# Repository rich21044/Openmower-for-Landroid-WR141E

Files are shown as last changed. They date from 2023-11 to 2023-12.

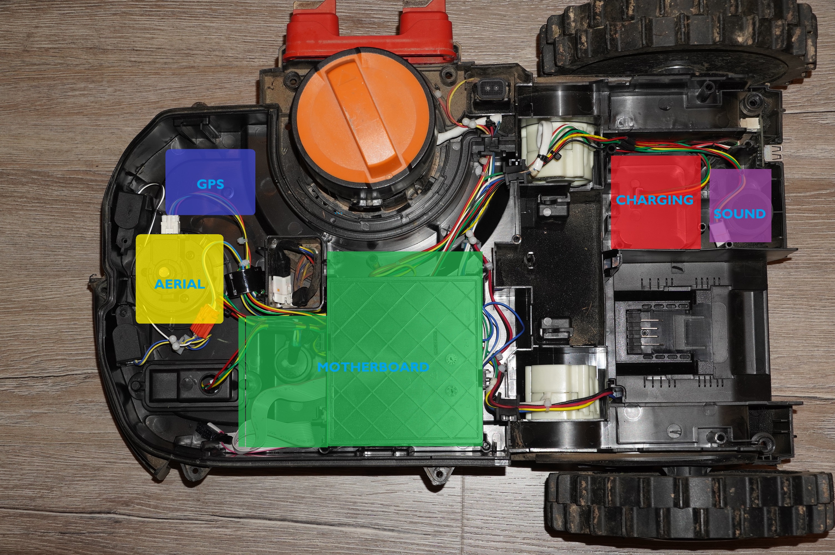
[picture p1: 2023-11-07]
Photos/WR141E Module locations.jpg

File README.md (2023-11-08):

# Openmower-for-Landroid-WR141E
Taking the hardware developed as part of ClemensElfleins work on Openmower and adapting it to fit a 2019 Landroid WR141E.

This is my first venture into Github so it might get a bit clunky. 
Usual rules apply.. please try to be constructive, I'm learning as I go so if you're going to leave some negative feedback have the grace to tell me why and how I can put it right.

The Openmower project by ClemensElflein started all this for me and I've been so fed up with the performance (or lack thereof) of my Landroid WR141E that I considered selling it and then just buying his kit
however, the Landroid does have cut to edge capability that the Open mower doesnt have and when all is said and done it probably works out at about the same cost.

According to the Gurus on Discord, the firmware in the Landroid is encoded, the data streams between the processors is encoded, the main processor is read locked and the JTAG interface is disabled.
I dont have the knowledge, expertise or equipment to hack into the exiitng Landroid hardware so the plan is to make best use of the Openmower hardware and firmware thats already been developed 
and port it into the Landroid WR141E.

The main thrust of this first stage of the project is to adjust the Openmower motherboard to fit into the available space in the Landroid.

I am also discussing development and asking questions on Discord as @Slartibartfast

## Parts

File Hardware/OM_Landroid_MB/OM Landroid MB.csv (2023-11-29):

Source: | C:\Users\matth\Documents\GitHub\Openmower-for-Landroid-WR141E\Hardware\OM_Landroid_MB\OM Landroid MB.kicad_sch
Date: | 28/11/2023 14:37
Tool: | Eeschema 7.0.8
Generator: | C:\Program Files\KiCad\7.0\bin\scripting\plugins/bom_csv_grouped_by_value_with_fp.py
Component Count: | 136
Ref | Qnty | Value | Price ea | Total | Vendor | Part No | Cmp name | Footprint | Description | Vendor | DNP
AC1201 | 1 | LSM6DSOTR | € 6.63 | € 6.63 | Digikey | 497-18367-1-ND | LSM6DSOTR | MyModules:LGA-14_2.5X3X0.86_ | IMUs - Inertial Measurement Units iNEMO inertial module: 3D accelerometer and 3D gyroscope
C1, C5, C25 | 3 | 100nF | € 0.09 | € 0.27 | Digikey | 1276-1003-1-ND | C | Capacitor_SMD:C_0805_2012Metric_Pad1.18x1.45mm_HandSolder | Unpolarized capacitor
C2, C4, C7, C8,C6,C3 | 6 | 220uF | € 1.33 | € 7.98 | Digikey | 10-EEH-AZA1V221BCT-ND | C_Polarized | Capacitor_THT:CP_Radial_D10.0mm_P5.00mm | Polarized capacitor LCSC 220uF 63V
C9, C23 | 2 | 680uF | € 2.47 | € 4.94 | Digikey | 10-EEH-ZS1V681UPCT-ND | C_Polarized | Capacitor_SMD:CP_Elec_10x10.5 | (LCSC 680uF 35V) Polarized capacitor SMD 10.30x10.30
C11, C12 | 2 | 4.7uF | € 0.28 | € 0.56 | Digikey | 1276-3179-1-nd | C | Capacitor_SMD:C_1206_3216Metric | Unpolarized capacitor
C13, C14 | 2 | 1uF | € 0.10 | € 0.20 | Digikey | 1276-1029-1-nd | C | Capacitor_SMD:C_0805_2012Metric | Unpolarized capacitor
C15, C18, C19, C24, C26 | 5 | 0.1uF | € 0.09 | € 0.45 | Digikey | 1276-1935-1-nd | C | Capacitor_SMD:C_0603_1608Metric | Unpolarized capacitor
C16, C20, C21, C22 | 4 | 22uF | € 0.32 | € 1.28 | Digikey | 1276-3148-1-nd | C | Capacitor_SMD:C_1206_3216Metric | Unpolarized capacitor
C17 | 1 | 2.2uF | € 0.17 | € 0.17 | Digikey | 1276-1183-1-nd | C | Capacitor_SMD:C_0603_1608Metric | Unpolarized capacitor
D1 | 1 | D_Schottky |  | € - |  |  | D_Schottky | Diode_SMD:D_SOD-123F | 60V 1A Schottky diode (LCSC Discontinued)
D4, D5, D6, D7, D8, D9, D10, D11, D12 | 9 | DNP |  | € - |  |  | D_TVS | Diode_SMD:D_SMB | Bidirectional transient-voltage-suppression diode
D13, D14 | 2 | DNP |  | € - |  |  | D_Zener | Diode_SMD:D_SOD-123F | Zener diode
D18, D19, D20 | 3 | DNP |  | € - |  |  | D_TVS | Diode_SMD:D_SMA | Bidirectional transient-voltage-suppression diode
D23 | 1 | LED | € 0.18 | € 0.18 | Digikey | 732-4983-1-ND | LED Green | LED_SMD:LED_0805_2012Metric | Light emitting diode
D25 | 1 | WS2812B | € 0.57 | € 0.57 | Digikey | 1568-COM-16347CT-ND | WS2812B | LED_SMD:LED_WS2812B_PLCC4_5.0x5.0mm_P3.2mm | RGB LED with integrated controller
F2, F4 | 2 | Fuse |  | € - |  |  | Fuse | MyModules:Fuseholder5x20_horiz_open_inline_Type-I | Fuse
IC1 | 1 | 74ALVC164245DGG,11 | € 1.00 | € 1.00 | Digikey | 1727-4290-1-ND | 74ALVC164245DGG,11 | 74ALVC164245DGG:SOP50P810X120-48N 48-TFSOP | 74ALVC164245 - 16-bit dual supply translating transceiver; 3-state@en-us
IC2 | 1 | TSC101CILT | € 2.03 | € 2.03 | Digikey | 497-6947-1-ND | TSC101CILT | TSC101CILT:SOT95P280X145-5N | TSC101CILT, Current Sensing Amplifier Single 5-Pin SOT-23
IC3 | 1 | MAX20405AFOC_VY+ | € 4.16 | € 4.16 | Digikey | 175-MAX20405AFOC/VY+-ND | MAX20405AFOC_VY+T | MAX2040:MAX2040 | 36V 4A/5A/6A Sync Low Iq Buck Converter in P90
J1 | 1 | Conn_01x02_Pin |  |  |  |  | Conn_01x02_Pin | Connector_JST:JST_XH_B2B-XH-AM_1x02_P2.50mm_Vertical | Generic connector, single row, 01x02, script generated
J2 | 1 | Conn_02x03_Top_Bottom | € 1.56 | € 1.56 | Digikey | A107227-ND | Conn_02x03_Odd_Even | Landroid_Motor_Conn:TE_179841 | Generic connector, double row, 02x03, odd/even pin numbering scheme (row 1 odd numbers, row 2 even numbers), script generated (kicad-library-utils/schlib/autogen/connector/)
J5, J6, J19 | 3 | Conn_01x04 |  |  |  |  | Conn_01x04 | Connector_JST:JST_XH_B4B-XH-A_1x04_P2.50mm_Vertical | Generic connector, single row, 01x04, script generated (kicad-library-utils/schlib/autogen/connector/)
J11, J12, J13, J14 | 4 | Conn_01x03_Male |  |  |  |  | Conn_01x03_Male | Connector_JST:JST_XH_B3B-XH-A_1x03_P2.50mm_Vertical | Generic connector, single row, 01x03, script generated (kicad-library-utils/schlib/autogen/connector/)
J15, J25, J27, J31, J33, J35, J39, J41, J43 | 9 | Conn_02x02_Female |  |  |  |  | Conn_02x02_Counter_Clockwise |  | Generic connector, double row, 02x02, counter clockwise pin numbering scheme (similar to DIP packge numbering), script generated (kicad-library-utils/schlib/autogen/connector/)
J17 | 1 | Conn_01x02 |  |  |  |  | Conn_01x02 | Connector_JST:JST_XH_B2B-XH-A_1x02_P2.50mm_Vertical | Generic connector, single row, 01x02, script generated (kicad-library-utils/schlib/autogen/connector/)
J21 | 1 | Extended GPIO Header Female | € 2.13 | € 2.13 | Digikey | 1568-PRT-16764-ND | Raspberry_Pi_2_3 | Connector_PinSocket_2.54mm:PinSocket_2x20_P2.54mm_Vertical Elevated Through hole | expansion header for Raspberry Pi 2 & 3
J22 | 1 | Conn_02x04_Odd_Even |  |  |  |  | Conn_02x04_Odd_Even | Connector_PinHeader_2.54mm:PinHeader_2x04_P2.54mm_Vertical | Generic connector, double row, 02x04, odd/even pin numbering scheme (row 1 odd numbers, row 2 even numbers), script generated (kicad-library-utils/schlib/autogen/connector/)
J24, J26, J32, J34, J40, J42, J47 | 7 | Conn_01x06_Female |  |  |  |  | Conn_01x06_Female |  | Generic connector, single row, 01x06, script generated (kicad-library-utils/schlib/autogen/connector/)
J28, J29, J36, J37, J44, J45 | 6 | Conn_01x05_Female |  |  |  |  | Conn_01x05_Female |  | Generic connector, single row, 01x05, script generated (kicad-library-utils/schlib/autogen/connector/)
J30, J38, J46 | 3 | Conn_01x09_Female |  |  |  |  | Conn_01x09_Female |  | Generic connector, single row, 01x09, script generated (kicad-library-utils/schlib/autogen/connector/)
J48, J49 | 2 | Conn_01x08_Female |  |  |  |  | Conn_01x08_Female |  | Generic connector, single row, 01x08, script generated (kicad-library-utils/schlib/autogen/connector/)
J50 | 1 | Conn_01x10_Female |  |  |  |  | Conn_01x10_Female |  | Generic connector, single row, 01x10, script generated (kicad-library-utils/schlib/autogen/connector/)
J51 | 1 | Conn_01x05_Socket |  |  |  |  | Conn_01x04_Socket | Connector_JST:JST_XH_B4B-XH-AM_1x04_P2.50mm_Vertical | Generic connector, single row, 01x04, script generated
J52 | 1 | Conn_01x05_Socket |  |  |  |  | Conn_01x05_Socket | Connector_JST:JST_XH_B5B-XH-A_1x05_P2.50mm_Vertical | Generic connector, single row, 01x05, script generated
J53 | 1 | Conn_01x04_Socket |  |  |  |  | Conn_01x04_Socket | Connector_JST:JST_XH_B4B-XH-AM_1x04_P2.50mm_Vertical | Generic connector, single row, 01x04, script generated
JC1 | 1 | Conn_01x03_Pin | € 0.98 | € 0.98 | Digikey | A107226-ND | Conn_01x03_Pin | Landroid_Motor_Conn:TE_179839 | Generic connector, single row, 01x03, script generated
JL1 | 1 | Conn_01x03_Pin | € 0.98 | € 0.98 | Digikey | A107226-ND | Conn_01x03_Pin | Landroid_Motor_Conn:TE_179839 | Generic connector, single row, 01x03, script generated
JP6 | 1 | SolderJumper_2_Bridged | € - |  | pcbway |  | SolderJumper_2_Bridged | Jumper:SolderJumper-2_P1.3mm_Bridged_RoundedPad1.0x1.5mm | Solder Jumper, 2-pole, closed/bridged
JP9 | 1 | SolderJumper_2_Open | € - |  | pcbway |  | SolderJumper_2_Open | Jumper:SolderJumper-2_P1.3mm_Open_RoundedPad1.0x1.5mm | Solder Jumper, 2-pole, open
JP12 | 1 | SolderJumper_3_Bridged12 | € - |  | pcbway |  | SolderJumper_3_Bridged12 | Jumper:SolderJumper-3_P1.3mm_Bridged12_Pad1.0x1.5mm | 3-pole Solder Jumper, pins 1+2 closed/bridged
JR1 | 1 | Conn_01x03_Pin | € 0.98 | € 0.98 | Digikey | A107226-ND | Conn_01x03_Pin | Landroid_Motor_Conn:TE_179839 | Generic connector, single row, 01x03, script generated
L1 | 1 | 6.8uH 5A | € 0.77 | € 0.77 | Digikey | 308-2467-1-ND | L | Inductor_SMD:L_Vishay_IHLP-2525 | Inductor
M1 | 1 | Fan |  |  |  |  | Fan | Connector_PinHeader_2.54mm:PinHeader_1x02_P2.54mm_Vertical | Fan
Q3, Q5 | 2 | BSS138 | € 0.15 | € 0.30 | Digikey | 4530-BSS138CT-ND | BSS138 | Package_TO_SOT_SMD:SOT-23 | 50V Vds, 0.22A Id, N-Channel MOSFET, SOT-23
Q6 | 1 | Q_PMOS_GDS | € 1.03 | € 1.03 | Digikey | IRFR5505PBFCT-ND | Q_PMOS_GDS | Package_TO_SOT_SMD:TO-252-2 | P-MOSFET transistor, gate/drain/source
R1, R2, R4, R26, R28, R40, R42, R48, R50 | 9 | 10k | € 0.09 | € 0.81 | Digikey | RMCF0805FT10K0CT-ND | R | Resistor_SMD:R_0805_2012Metric_Pad1.20x1.40mm_HandSolder | Resistor
R5, R27 | 2 | 150R | € 0.09 | € 0.18 | Digikey | RMCF0805FT150RCT-ND | R | Resistor_SMD:R_0805_2012Metric_Pad1.20x1.40mm_HandSolder | Resistor
R7, R13, R18, R43, R45, R47 | 6 | 1k | € 0.09 | € 0.54 | Digikey | 311-1.00KCRCT-ND | R | Resistor_SMD:R_0805_2012Metric_Pad1.20x1.40mm_HandSolder | Resistor
R8 | 1 | 5k | € 0.14 | € 0.14 | Digikey | 541-CRCW08055K00FKTACT-ND | R | Resistor_SMD:R_0805_2012Metric_Pad1.20x1.40mm_HandSolder | Resistor
R44, R46 | 2 | 47k | € 0.13 | € 0.26 | Digikey | 1276-5377-1-ND | R | Resistor_SMD:R_0805_2012Metric_Pad1.20x1.40mm_HandSolder | Resistor
R49 | 1 | 4k7 | € 0.09 | € 0.09 | Digikey | 541-4131-1-ND | R | Resistor_SMD:R_0805_2012Metric_Pad1.20x1.40mm_HandSolder | Resistor
R51 | 1 | 0.003R | € 0.55 | € 0.55 | Digikey | YAG2138CT-ND | R | Resistor_SMD:R_2512_6332Metric_Pad1.40x3.35mm_HandSolder | Resistor
SW1 | 1 | MK-11C04-G013 |  |  |  |  | MK-11C04-G013 | lcsc:SW-SMD_MK-11C04-G013
TP1, TP2, TP5 | 3 | TestPoint |  | € - |  |  | TestPoint | TestPoint:TestPoint_Pad_D2.0mm | test point
U2 | 1 | MCP604 | € 1.43 | € 1.43 | Digikey | MCP604T-E/SLCT-ND | MCP604 | Package_SO:SOIC-14_3.9x8.7mm_P1.27mm | Quad 2.7V to 6.0V Single Supply CMOS Op Amps, DIP-14/SOIC-14/TSSOP-14
U3 | 1 | SIP32509DT | € 0.44 | € 0.44 | Digikey | SIP32509DT-T1-GE3CT-ND | SIP32509DT | Package_TO_SOT_SMD:SOT-23-6
U4, U5, U6 | 3 | xESC2 |  | € - |  |  | xESC2 | xESC2:xESC2
U7 | 1 | SN74LV1T34DBVR | € 0.36 | € 0.36 | Digikey | 296-37176-1-ND | SN74LV1T34DBV | Package_TO_SOT_SMD:SOT-23-5 | Single Power Supply, Single Buffer GATE, CMOS Logic, Level Shifter, SOT-23-5
U9, U10 | 2 | 74HC4051 | € 0.41 | € 0.82 | Digikey | 1727-3064-1-ND | 74HC4051 | Package_SO:SSOP-16_4.4x5.2mm_P0.65mm | 8-channel analog multiplexer/demultiplexer, DIP-16/SOIC-16/TSSOP-16
U11 | 1 | Pico |  |  |  |  | RaspberryPi-PicoW | PicoW:Raspberry_Pi_Pico_THT | Raspberry Pi Pico W, RP2040-based microcontroller board with wireless
XA1 | 1 | Arduino_Uno_Shield |  |  |  |  | Arduino_Uno_Shield | MyModules:Arduino_Uno_Shield

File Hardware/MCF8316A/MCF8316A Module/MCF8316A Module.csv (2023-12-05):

Source: | C:\Users\matth\Documents\GitHub\Openmower-for-Landroid-WR141E\Hardware\MCF8316A\MCF8316A Module\MCF8316A Module.kicad_sch
Date: | 30/11/2023 17:51:32
Tool: | Eeschema 7.0.8
Generator: | C:\Program Files\KiCad\7.0\bin\scripting\plugins/bom_csv_grouped_by_value.py
Component Count: | 25
Collated Components:
Item | Qty | Reference(s) | Value | LibPart | Footprint | Datasheet | DNP | Digikey
1 | 1 | C1 | 1uF 50v | Device:C | Capacitor_SMD:C_0805_2012Metric | ~ |  | 1276-1029-1-ND
2 | 1 | C2 | 47nF 50V | Device:C | Capacitor_SMD:C_0805_2012Metric | ~ |  | 1276-1250-1-ND
3 | 1 | C3 | 0.1uf 50v | Device:C | Capacitor_SMD:C_0805_2012Metric | ~ |  | 1276-1003-1-ND
4 | 1 | C4 | 330uf 50v | Device:C_Polarized | Capacitor_SMD:C_Elec_10x10.2 | https://mm.digikey.com/Volume0/opasdata/d220001/medias/docus/935/MZR_Series_DS.pdf |  | 565-EMZR500ARA331MJA0GCT-ND
5 | 1 | C5 | 22uF 10v | Device:C | Capacitor_SMD:C_0805_2012Metric | ~ |  | 1276-2910-1-ND
6 | 1 | C6 | 1uF 6.3V | Device:C | Capacitor_SMD:C_0805_2012Metric | ~ |  | 399-13161-1-ND
7 | 1 | C7 | 1uF 6.3v | Device:C | Capacitor_SMD:C_0805_2012Metric | ~ |  | 399-13161-1-ND
8 | 1 | D1 | 3mm Red | Device:LED | LED_THT:LED_D3.0mm | ~ |  | 1080-1048-1-ND
9 | 1 | D2 | 3mm Grn | Device:LED | LED_THT:LED_D3.0mm | ~ |  | 516-1792-1-ND
10 | 4 | FID1, FID2, FID3, FID4 | Fiducial | Mechanical:Fiducial |  | ~
11 | 5 | J1, J2, J3, J4, J5 | Conn_01x04_Pin | Connector:Conn_01x04_Pin | Connector_PinHeader_2.54mm:PinHeader_1x04_P2.54mm_Vertical | ~ |  | 952-3273-ND
12 | 1 | J6 | Conn_01x10_Pin | Connector:Conn_01x10_Pin | Connector_PinHeader_2.54mm:PinHeader_1x10_P2.54mm_Vertical | ~
13 | 1 | R1 | 22R | Device:R | Resistor_SMD:R_0805_2012Metric | ~ |  | RMCF0805FT22R0CT-ND
14 | 1 | R2 | 1.54k | Device:R | Resistor_SMD:R_0805_2012Metric | ~ |  | RMCF0805FT1K54CT-ND
15 | 2 | R3, R4 | 5k | Device:R | Resistor_SMD:R_0805_2012Metric | ~ |  | 541-CRCW08055K00FKTACT-ND
16 | 1 | R5 | 1.6k | Device:R | Resistor_SMD:R_0805_2012Metric | ~ |  | RMCF0805FT1K60CT-ND
17 | 1 | U1 | MCF8316A1VRGFR | MCF8316A:MCF8316A1VRGFR | VQFN40_RGF_TEX | MCF8316A1VRGFR |  | 296-MCF8316A1VRGFRCT-ND

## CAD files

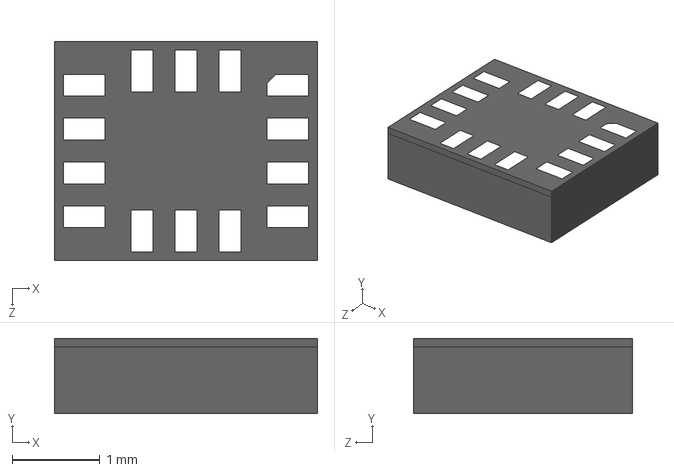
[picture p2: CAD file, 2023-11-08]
Hardware/OM_Landroid_MB/LSM6DSOTR/LSM6DSOTR.stp
3.00 x 0.86 x 2.50 mm

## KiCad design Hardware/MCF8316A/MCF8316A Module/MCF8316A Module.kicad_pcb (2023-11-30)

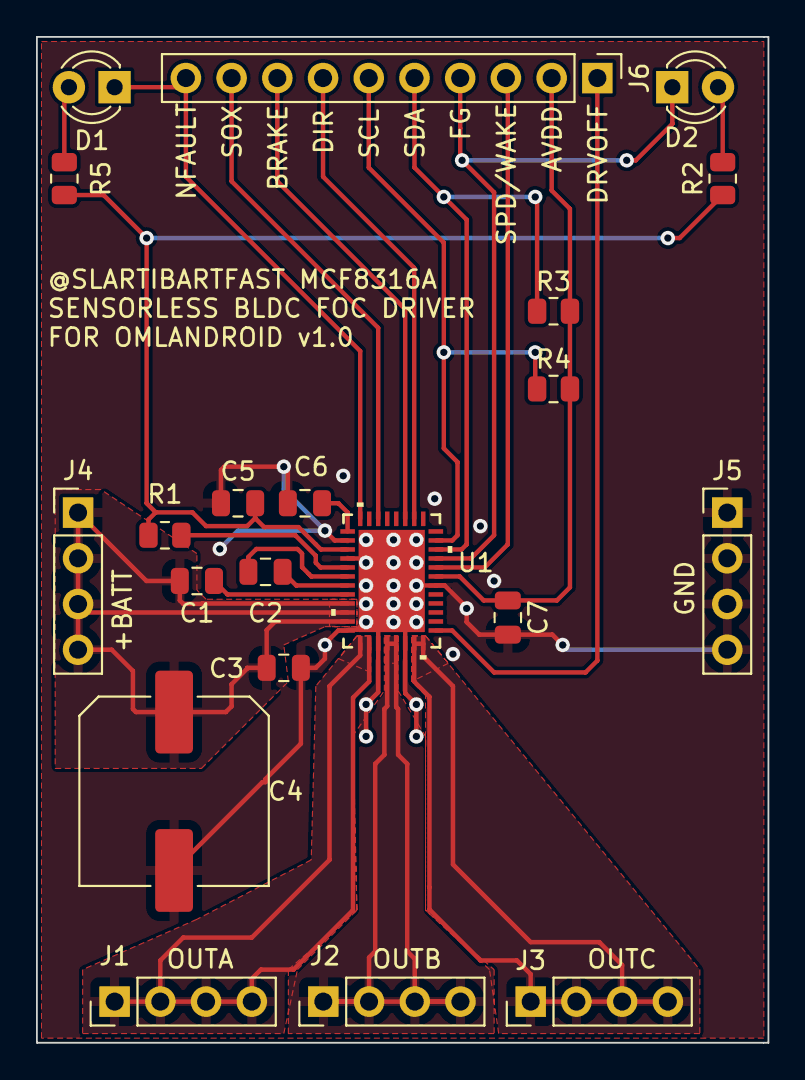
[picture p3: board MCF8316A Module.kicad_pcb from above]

Board: 2 copper layers, 40.6 x 55.9 mm, 21 parts (0 on the bottom side), 23 nets.

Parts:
C1: 1uF 50v; C_0805_2012Metric
C2: 47nF 50V; C_0805_2012Metric
C3: 0.1uf 50v; C_0805_2012Metric
C4: 330uf 50v; C_Elec_10x10.2
C5: 22uF 10v; C_0805_2012Metric
C6: 1uF 6.3V; C_0805_2012Metric
C7: 1uF 6.3v; C_0805_2012Metric
D1: 3mm Red; LED_D3.0mm
D2: 3mm Grn; LED_D3.0mm
J1, J2, J3, J4, J5: Conn_01x04_Pin; PinHeader_1x04_P2.54mm_Vertical
J6: Conn_01x10_Pin; PinHeader_1x10_P2.54mm_Vertical
R1: 22R; R_0805_2012Metric
R2: 1.54k; R_0805_2012Metric
R3, R4: 5k; R_0805_2012Metric
R5: 1.6k; R_0805_2012Metric
U1: MCF8316A1VRGFR; VQFN40_RGF_TEX

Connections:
+BATT: C1.1, C3.1, C4.1, J4.1, J4.2, J4.3, J4.4, U1.9 (VM), U1.10 (VM), U1.11 (VM)
GND: C3.2, C4.2, C5.2, C6.2, C7.2, J5.1, J5.2, J5.3, J5.4, U1.2 (DGND), U1.4 (GND_BK), U1.12 (PGND), U1.15 (PGND), U1.18 (PGND), U1.26 (AGND), U1.41 (GND)
unnamed: D1.2 (A), R5.2
unnamed: D1.1 (K), J6.10, U1.40 (NFAULT)
unnamed: D2.2 (A), R2.2
unnamed: D2.1 (K), J6.4, U1.29 (FG)
unnamed: J1.1, J1.2, J1.3, J1.4, U1.13 (OUTA), U1.14 (OUTA)
unnamed: J2.1, J2.2, J2.3, J2.4, U1.16 (OUTB), U1.17 (OUTB)
unnamed: J3.1, J3.2, J3.3, J3.4, U1.19 (OUTC), U1.20 (OUTC)
unnamed: J6.1, U1.21 (DRVOFF)
unnamed: C7.1, J6.2, R3.2, R4.2, U1.27 (AVDD)
unnamed: J6.3, U1.28 (SPEED/WAKE)
unnamed: J6.5, R3.1, U1.30 (SDA)
unnamed: J6.6, R4.1, U1.31 (SCL)
unnamed: J6.7, U1.34 (DIR)
unnamed: J6.8, U1.35 (BRAKE)
unnamed: J6.9, U1.38 (SOX)
unnamed: C1.2, U1.8 (CP)
unnamed: C2.1, U1.7 (CPH)
unnamed: C2.2, U1.6 (CPL)
unnamed: C6.1, U1.1 (DVDD)
unnamed: C5.1, R1.1, R2.1, R5.1, U1.3 (FB_BK)
unnamed: R1.2, U1.5 (SW_BK)

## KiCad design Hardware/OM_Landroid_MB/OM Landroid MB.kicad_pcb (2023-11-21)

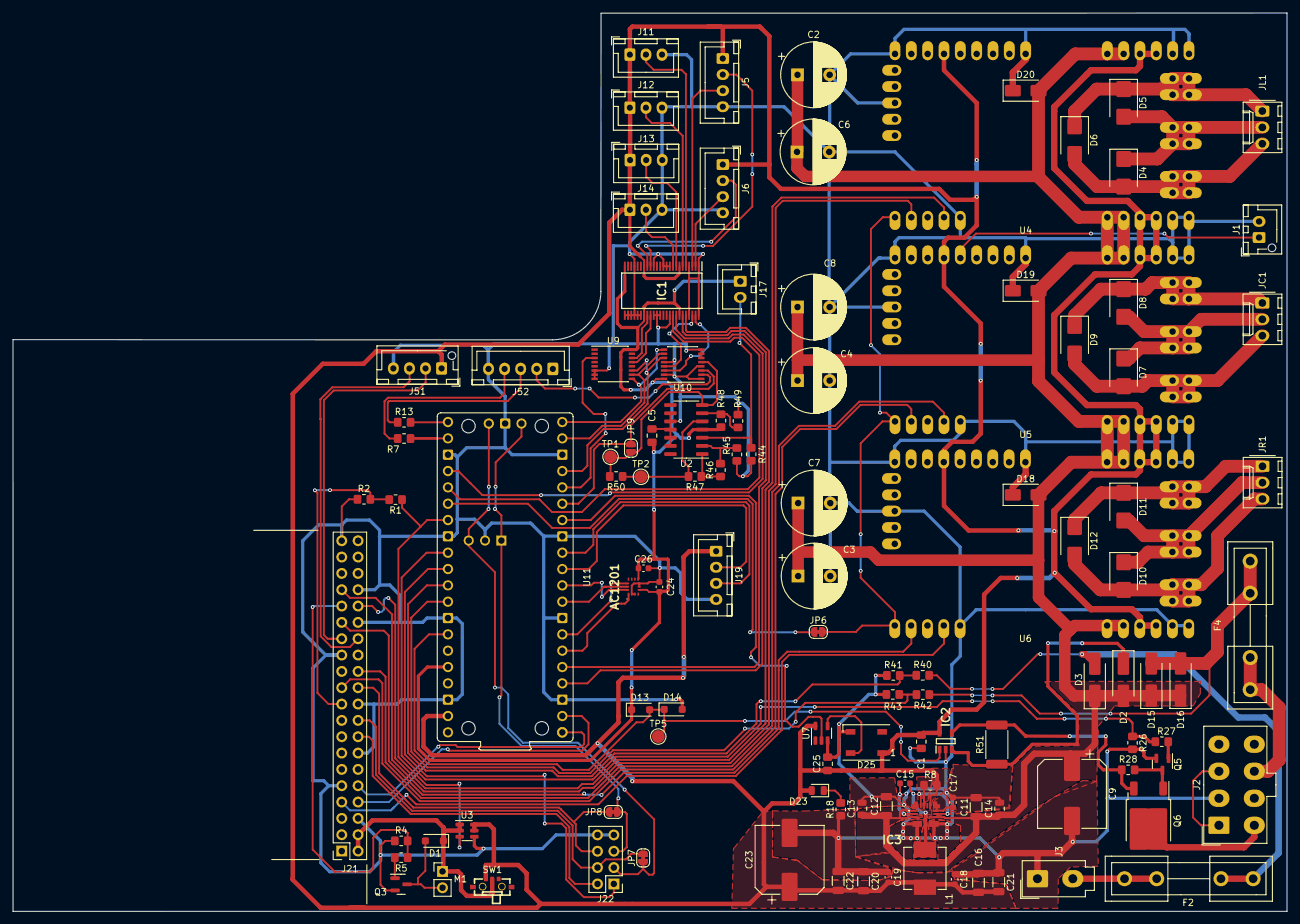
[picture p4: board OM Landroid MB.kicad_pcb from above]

Board: 2 copper layers, 198.1 x 139.7 mm, 115 parts (0 on the bottom side), 98 nets.

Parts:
AC1201: LSM6DSOTR; LGA-14_2.5X3X0.86_
C1, C5, C25: 100nF; C_0805_2012Metric_Pad1.18x1.45mm_HandSolder
C2, C3, C4, C6, C7, C8: 220uF; CP_Radial_D10.0mm_P5.00mm
C9, C23: 680uF; CP_Elec_10x12.5
C11, C12: 4.7uF; C_1206_3216Metric
C13, C14: 1uF; C_0805_2012Metric
C15, C18, C19, C24, C26: 0.1uF; C_0603_1608Metric
C16, C20, C21, C22: 22uF; C_1206_3216Metric
C17: 2.2uF; C_0603_1608Metric
D1: D_Schottky; D_SOD-123F
D2, D3, D15, D16: D_Schottky; D_SMA_Handsoldering
D4, D5, D6, D7, D8, D9, D10, D11, D12: DNP; D_SMB
D13, D14: DNP; D_SOD-123F
D18, D19, D20: DNP; D_SMA
D23: LED; LED_0805_2012Metric
D25: WS2812B; LED_WS2812B_PLCC4_5.0x5.0mm_P3.2mm
F2, F4: Fuse; Fuseholder5x20_horiz_open_inline_Type-I
IC1: 74ALVC164245DGG,11; SOP50P810X120-48N
IC2: TSC101CILT; SOT95P280X145-5N
IC3: MAX20405AFOF_VY+T; MAX2040
J1: Conn_01x02_Pin; JST_XH_B2B-XH-AM_1x02_P2.50mm_Vertical
J2: Conn_02x04_Top_Bottom; Molex_Mini-Fit_Jr_5566-08A_2x04_P4.20mm_Vertical
J3: Conn_01x02; Molex_Mini-Fit_Jr_5566-02A_2x01_P4.20mm_Vertical
J5, J6, J19: Conn_01x04; JST_XH_B4B-XH-A_1x04_P2.50mm_Vertical
J11, J12, J13, J14: Conn_01x03_Male; JST_XH_B3B-XH-A_1x03_P2.50mm_Vertical
J17: Conn_01x02; JST_XH_B2B-XH-A_1x02_P2.50mm_Vertical
J21: Raspberry_Pi_2_3; PinSocket_2x20_P2.54mm_Vertical
J22: Conn_02x04_Odd_Even; PinHeader_2x04_P2.54mm_Vertical
J51: Conn_01x05_Socket; JST_XH_B4B-XH-AM_1x04_P2.50mm_Vertical
J52: Conn_01x05_Socket; JST_XH_B5B-XH-A_1x05_P2.50mm_Vertical
JC1: Conn_01x03_Pin; Molex_KK-254_AE-6410-03A_1x03_P2.54mm_Vertical
JL1: Conn_01x03_Pin; Molex_KK-254_AE-6410-03A_1x03_P2.54mm_Vertical
JP6, JP7, JP8: SolderJumper_2_Bridged; SolderJumper-2_P1.3mm_Bridged_RoundedPad1.0x1.5mm
JP9: SolderJumper_2_Open; SolderJumper-2_P1.3mm_Open_RoundedPad1.0x1.5mm
JR1: Conn_01x03_Pin; Molex_KK-254_AE-6410-03A_1x03_P2.54mm_Vertical
L1: 4.7uH 5A; L_Vishay_IHLP-2525
M1: Fan; PinHeader_1x02_P2.54mm_Vertical
Q3, Q5: BSS138; SOT-23
Q6: Q_PMOS_GDS; TO-252-2
R1, R2, R4, R26, R28, R40, R42, R48, R50: 10k; R_0805_2012Metric_Pad1.20x1.40mm_HandSolder
R5, R27: 150; R_0805_2012Metric_Pad1.20x1.40mm_HandSolder
R7, R13, R18, R41, R43, R45, R47: 1k; R_0805_2012Metric_Pad1.20x1.40mm_HandSolder
R8: 5k; R_0805_2012Metric_Pad1.20x1.40mm_HandSolder
R44, R46: 47k; R_0805_2012Metric_Pad1.20x1.40mm_HandSolder
R49: 4k7; R_0805_2012Metric_Pad1.20x1.40mm_HandSolder
R51: 0.003R; R_2512_6332Metric_Pad1.40x3.35mm_HandSolder
SW1: MK-11C04-G013; SW-SMD_MK-11C04-G013
TP1, TP2, TP5: TestPoint; TestPoint_Pad_D2.0mm
U2: MCP604; SOIC-14_3.9x8.7mm_P1.27mm
U3: SIP32509DT; SOT-23-6
U4, U5, U6: xESC2
U7: SN74LV1T34DBV; SOT-23-5
U9, U10: 74HC4051; SSOP-16_4.4x5.2mm_P0.65mm
U11: Pico; Raspberry_Pi_Pico_THT

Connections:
+3V3: AC1201.5 (VDDIO), AC1201.8 (VDD), C5.2, C24.1, C26.1, D13.1 (K), IC1.24 (2DIR), IC1.31 (VCC(A)_1), IC1.42 (VCC(A)_2), J17.1, R48.2, U2.4 (V+), U9.16 (VCC), U10.16 (VCC), U11.36 (3V3)
+5V: C1.1, C16.2, C18.2, C19.2, C20.2, C21.2, C22.2, C23.1, C25.1, D23.2 (A), D25.1 (VDD), IC1.7 (VCC(B)_1), IC1.18 (VCC(B)_2), IC2.5 (VCC), IC3.13 (OUT), J5.1, J6.1, J11.1, J12.1, J13.1, J14.1, J19.1, J51.1, L1.2, R8.2, SW1.1, U3.5 (VIN), U3.6 (VIN), U4.5V, U5.5V, U6.5V, U7.5 (VCC), U11.39 (VSYS)
/CHARGE_CURRENT: D13.2 (A), D14.1 (K), IC2.1 (OUT), TP5.1, U11.34 (GPIO28_ADC2)
/ESCs/ESC_SHUTDOWN: JP6.1 (A), U11.26 (GPIO20)
/ESCs/MC_PHASE_U: D7.2 (A2), D9.2 (A2), JC1.3, U5.U
/ESCs/MC_PHASE_V: D7.1 (A1), D8.2 (A2), JC1.2, U5.V
/ESCs/MC_PHASE_W: D8.1 (A1), D9.1 (A1), JC1.1, U5.W
/ESCs/MC_RX: J21.24 (~CE0/GPIO8), U5.14 (NCS/RX)
/ESCs/MC_TEMP: J1.1, U5.3 (TEMPERATURE)
/ESCs/MC_TX: J21.21 (MISO0/GPIO9), U5.12 (MOSI/TX)
/ESCs/ML_PHASE_U: D4.2 (A2), D6.2 (A2), JL1.3, U4.U
/ESCs/ML_PHASE_V: D4.1 (A1), D5.2 (A2), JL1.2, U4.V
/ESCs/ML_PHASE_W: D5.1 (A1), D6.1 (A1), JL1.1, U4.W
/ESCs/ML_RX: J21.32 (PWM0/GPIO12), U4.14 (NCS/RX)
/ESCs/ML_TX: J21.33 (PWM1/GPIO13), U4.12 (MOSI/TX)
/ESCs/MR_PHASE_U: D10.2 (A2), D12.2 (A2), JR1.3, U6.U
/ESCs/MR_PHASE_V: D10.1 (A1), D11.2 (A2), JR1.2, U6.V
/ESCs/MR_PHASE_W: D11.1 (A1), D12.1 (A1), JR1.1, U6.W
/ESCs/MR_RX: J21.7 (GCLK0/GPIO4), U6.14 (NCS/RX)
/ESCs/MR_TX: J21.29 (GCLK1/GPIO5), U6.12 (MOSI/TX)
/IMU/MISO: AC1201.1 (SDO/SA0), U11.6 (GPIO4)
/IMU/MOSI: AC1201.14 (SDA), U11.10 (GPIO7)
/IMU/SCK: AC1201.13 (SCL), U11.9 (GPIO6)
/IMU/~CS: AC1201.12 (CS), U11.7 (GPIO5)
/RAIN_DETECTED: JP9.1 (A), R50.2, TP1.1, U2.7, U10.5 (A5)
/RaspberryPi/PICO_RESET: J22.1, U11.30 (RUN)
/RaspberryPi/PICO_SWCLK: J22.5, JP8.1 (A), U11.41 (SWCLK)
/RaspberryPi/PICO_SWDIO: J22.3, JP7.1 (A), U11.43 (SWDIO)
/RaspberryPi/POWER_EN: R1.1, U3.3 (ENABLE), U11.27 (GPIO21)
/RaspberryPi/RASPI_FAN_ON: J21.31 (GCLK2/GPIO6), R4.2, R5.1
/RaspberryPi/RASPI_POWER: D1.1 (K), J21.2 (5V), J21.4 (5V), M1.1 (+), SW1.C, U3.1 (VOUT), U3.2 (VOUT)
/RaspberryPi/UART0_RXD: J21.10 (GPIO15/RXD), U11.1 (GPIO0)
/RaspberryPi/UART0_TXD: J21.8 (GPIO14/TXD), U11.2 (GPIO1)
/RaspberryPi/UART1_RXD: J21.28 (ID_SC/GPIO1), J51.3
/RaspberryPi/UART1_TXD: J21.27 (ID_SD/GPIO0), J51.2
/RobotConnectors/CHARGE_SHUNT_MINUS: IC2.4 (VM), Q6.3 (S), R28.1, R51.2
/RobotConnectors/CHARGE_SHUNT_PLUS: D2.1 (K), IC2.3 (VP), R51.1
/RobotConnectors/ENABLE_CHARGE: R26.1, R27.1, U11.29 (GPIO22)
/RobotConnectors/HALL_SWITCH_1: IC1.41 (1A4), U11.24 (GPIO18)
/RobotConnectors/HALL_SWITCH_1_5V: IC1.8 (1B4), J13.2
/RobotConnectors/HALL_SWITCH_2: IC1.40 (1A5), U11.25 (GPIO19)
/RobotConnectors/HALL_SWITCH_2_5V: IC1.9 (1B5), J14.2
/RobotConnectors/HALL_SWITCH_3: IC1.43 (1A3), U11.5 (GPIO3)
/RobotConnectors/HALL_SWITCH_3_5V: IC1.6 (1B3), J12.2
/RobotConnectors/HALL_SWITCH_4: IC1.44 (1A2), U11.4 (GPIO2)
/RobotConnectors/HALL_SWITCH_4_5V: IC1.5 (1B2), J11.2
/RobotConnectors/LED_RX: J19.2, U11.11 (GPIO8)
/RobotConnectors/LED_TX: J19.3, U11.12 (GPIO9)
/RobotConnectors/MosfetSwitch/VOUT: J2.5, Q6.2 (D)
/RobotConnectors/RAIN-: J17.2, R44.2, U2.3 (+)
/RobotConnectors/SOUND_BUSY: J52.2, U10.2 (A6)
/RobotConnectors/SOUND_RX: R13.2, U11.21 (GPIO16)
/RobotConnectors/SOUND_TX: R7.2, U11.22 (GPIO17)
/RobotConnectors/USS_1_ECHO: IC1.46 (1A1), U10.13 (A0)
/RobotConnectors/USS_1_ECHO_5V: IC1.3 (1B1), J5.3
/RobotConnectors/USS_1_TRIGGER: IC1.33 (2A2), U9.13 (A0)
/RobotConnectors/USS_1_TRIGGER_5V: IC1.16 (2B2), J5.2
/RobotConnectors/USS_2_ECHO: IC1.47 (1A0), U10.14 (A1)
/RobotConnectors/USS_2_ECHO_5V: IC1.2 (1B0), J6.3
/RobotConnectors/USS_2_TRIGGER: IC1.32 (2A3), U9.14 (A1)
/RobotConnectors/USS_2_TRIGGER_5V: IC1.17 (2B3), J6.2
/RobotConnectors/V_BATTERY: D15.2 (A), D16.2 (A), F4.2, R42.2
/RobotConnectors/V_CHARGE: D3.2 (A), F2.1, R40.2
/pico/MUX_ADDRESS_0: U9.11 (S0), U10.11 (S0), U11.17 (GPIO13)
/pico/MUX_ADDRESS_1: U9.10 (S1), U10.10 (S1), U11.19 (GPIO14)
/pico/MUX_ADDRESS_2: U9.9 (S2), U10.9 (S2), U11.20 (GPIO15)
/pico/MUX_INPUT: JP9.2 (B), U10.3 (A), U11.15 (GPIO11)
/pico/MUX_OUTPUT: U9.3 (A), U11.16 (GPIO12)
/pico/V_CHARGE: R40.1, R41.2, U11.31 (GPIO26_ADC0)
/pico/V_IN: R42.1, R43.2, U11.32 (GPIO27_ADC1)
GND: AC1201.2 (SDX), AC1201.3 (SCX), AC1201.6 (GND_1), AC1201.7 (GND_2), C1.2, C2.2, C3.2, C4.2, C5.1, C6.2, C7.2, C8.2, C9.2, C11.2, C12.2, C13.2, C14.2, C16.1, C17.2, C18.1, C19.1, C20.1, C21.1, C22.1, C23.2, C24.2, C25.2, C26.2, D14.2 (A), D18.1 (A1), D19.1 (A1), D20.1 (A1), D25.3 (VSS), IC1.1 (1DIR), IC1.4 (GND_1), IC1.10 (GND_2), IC1.11 (1B6), IC1.12 (1B7), IC1.15 (GND_3), IC1.21 (GND_4), IC1.25 (~2OE), IC1.26 (2A7), IC1.27 (2A6), IC1.28 (GND_5), IC1.29 (2A5), IC1.30 (2A4), IC1.34 (GND_6), IC1.35 (2A1), IC1.36 (2A0), IC1.39 (GND_7), IC1.45 (GND_8), IC1.48 (~1OE), IC2.2 (GND), IC3.4 (PGND_1), IC3.5 (PGND_2), IC3.7 (PGND_3), IC3.8 (PGND_4), J1.2, J2.2, J3.1, J5.4, J6.4, J11.3, J12.3, J13.3, J14.3, J19.4, J21.6 (GND), J21.9 (GND), J21.14 (GND), J21.20 (GND), J21.25 (GND), J21.30 (GND), J21.34 (GND), J21.39 (GND), J22.7, J22.8, J51.4, J52.5, Q3.2 (S), Q5.2 (S), R2.1, R4.1, R18.1, R26.2, R41.1, R43.1, R44.1, R45.1, R49.2, U2.9 (-), U2.10 (+), U2.11 (V-), U2.12 (+), U2.13 (-), U3.4 (GND), U4.GND, U5.GND, U6.GND, U7.3 (GND), U9.6 (~E), U9.7 (VEE), U9.8 (GND), U10.1 (A4), U10.4 (A7), U10.6 (~E), U10.7 (VEE), U10.8 (GND), U10.12 (A3), U10.15 (A2), U11.3 (GND), U11.8 (GND), U11.13 (GND), U11.18 (GND), U11.23 (GND), U11.28 (GND), U11.33 (AGND), U11.38 (GND), U11.42 (SWGND)
unnamed: D1.2 (A), M1.2 (-), Q3.3 (D)
unnamed: D23.1 (K), R18.2
unnamed: D25.4 (DIN), U7.4 (Y)
unnamed: C17.1, IC3.11 (BIAS), IC3.12 (FB_1)
unnamed: C15.1, IC3.2 (BST)
unnamed: IC3.10 (GND), IC3.16 (SYNC)
unnamed: C15.2, IC3.6 (LX_1), L1.1
unnamed: IC3.15 (PGOOD), R8.1
unnamed: J2.1, J2.3
unnamed: F4.1, J2.7
unnamed: F2.2, J3.2
unnamed: J21.16 (GPIO23), J22.2
unnamed: J21.18 (GPIO24), J22.4, JP7.2 (B)
unnamed: J21.22 (GPIO25), J22.6, JP8.2 (B)
unnamed: J21.19 (MOSI0/GPIO10), R1.2, R2.2
unnamed: J52.3, R13.1
unnamed: J52.4, R7.1
unnamed: JP6.2 (B), U4.11 (MISO), U5.11 (MISO), U6.11 (MISO)
unnamed: Q3.1 (G), R5.2
unnamed: Q5.3 (D), Q6.1 (G), R28.2
unnamed: Q5.1 (G), R27.2
unnamed: R46.1, R47.1, U2.1
unnamed: R45.2, R46.2, U2.2 (-)
unnamed: R47.2, R50.1, TP2.1, U2.5 (+)
unnamed: R48.1, R49.1, U2.6 (-)
unnamed: U7.2 (A), U11.14 (GPIO10)
V_BATT: C2.1, C3.1, C4.1, C6.1, C7.1, C8.1, C9.1, C11.1, C12.1, C13.1, C14.1, D2.2 (A), D3.1 (K), D15.1 (K), D16.1 (K), D18.2 (A2), D19.2 (A2), D20.2 (A2), IC3.1 (EN), IC3.3 (SUP_1), IC3.9 (SUP_2), U4.VM (VIN), U5.VM (VIN), U6.VM (VIN)

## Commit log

2023-11-09 Add files via upload
    Updates for Schematic and PCB with additional footprint for the TE-179839 3 pin connector which matches the original motor connectors - thus avoiding the need to change these when installing the new Mobo.
2023-11-10 Schematic update
    Getting to grips with Github desktop...I worked out that I'd changed the PCB but had forgotten to update the schematic file for Kicad for the connectors ....so there was a disconnect :)
    [RobotConnectors.kicad_sch]
2023-11-12 Weekend progress
    [OM Landroid MB.kicad_pcb, OM Landroid MB.kicad_sch, RaspberryPi.kicad_sch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]
2023-11-14 Daily update
    [OM Landroid MB.kicad_pcb]
2023-11-22 Finished Mainboard
    Finished Mainboard redesign for OM Landroid
    [OM Landroid MB.kicad_sch, RaspberryPi.kicad_sch, RobotConnectors.kicad_sch]
2023-11-26 Updates and revisions to charging connections
    [OM Landroid MB.kicad_sch, RobotConnectors.kicad_sch, pico.kicad_sch]
2023-11-29 Changes to align BOM with board
    Changes were needed to align the BOM content with the board and to reflect component availability from Digikey
    [OM Landroid MB.csv, RaspberryPi.kicad_sch, RobotConnectors.kicad_sch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]
2023-11-30 MCF8316A test board produced and sent to PCBway
    [MCF8316A Module.kicad_pcb, MCF8316A Module.kicad_sch]
2023-12-05 MCF8316a driver board photo added
    Fresh from PCBway
    [MCF8316A Module.csv]
2024-04-18 Create MCF8316A Registers.xlsx
    [MCF8316A Registers.xlsx]
